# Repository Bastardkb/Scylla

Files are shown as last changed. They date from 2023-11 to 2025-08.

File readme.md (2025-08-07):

# Scylla

A modern low-profile ergonomic split keyboard, with a number row and a feature-full thumb cluster.

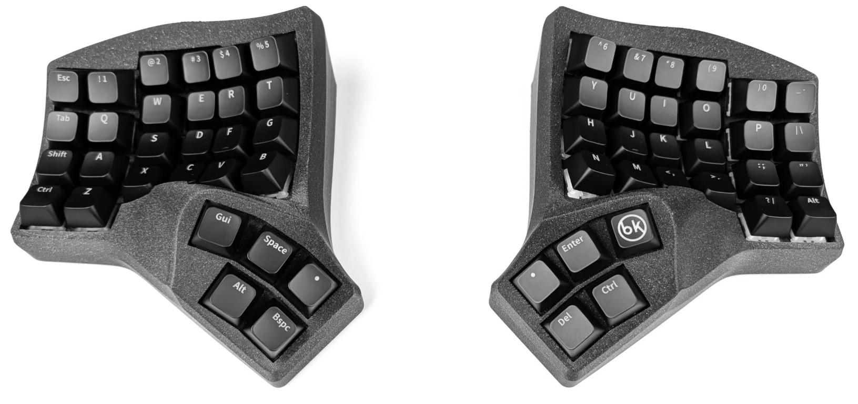
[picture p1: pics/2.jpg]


# Required components

## Electronic components

You will need to order the parts from a shop, and order some PCBs directly from the manufacturer.

Parts list:

| Part name | Amount | Link |
| --- | --- | --- |
| Flexible PCB for the plate | 2 | https://github.com/Bastardkb/Scylla-PCB-Plate |
| Flexible PCB for the thumbs | 2 | https://github.com/Bastardkb/Scylla-PCB-thumb-cluster |
| Splinktegrated* | 2 | https://github.com/bastardkb/splinktegrated |
| SOD123 Diodes | 10 | |
| BAT54C Diodes | 24 | |
| Cables | | 28 AWG recommended |
| M4 8mm Torx Screw | 16 | Conrad |
| M4 screw insert, M4 X D6.0 X L5.0 | 16 | https://fr.aliexpress.com/item/4000232925592.html?spm=a2g0s.12269583.0.0.6aef4f282LZO4v |
| Audio jack, SMD | 2 | |
| Button, 4x4x1.5 | 2 | https://www.aliexpress.com/item/1005001304569553.html?spm=a2g0s.9042311.0.0.27424c4dDwgcp7 |

*Alternatively, you can use the [Elite-C holder](https://github.com/Bastardkb/Elite-C-holder) with the [splinky](https://github.com/bastardkb/splinky) or any other [compatible board](https://docs.bastardkb.com/hw/rp2040-community.html). 

If you don't want to source the flexible PCBs, you can also use either amoebas or handwire.

If you want RGB, you will also need:

| Part name | Amount | Link |
| --- | --- | --- |
| SK6812 Mini-E LEDs | 58 | Aliexpress |
| Capacitor, 1uF | 4 | 1206 |
| Resistor, 330Ohms | 4 | 1206 |
| Wires | | 28 AWG recommended, Black, Red, Color |
| Ribbon cables Flexstrip | 6 | |

## Print the case

The STL files are included in this Github.
Feel free to use and modify them at length. The files are on a non-commercial license, so this is for personal projects only - please do not use those to sell them.

Please find detailed instructions on how to print the case on the online instructions linked below.

### Tent mount plate
This option allows the keyboard to be mounted to standard camera gear tripods and mounts.  
A 1/4 - 20 UNC 7.6 mm deep heat insert is needed.  

## Get a kit from BastardKB

You can get a full Kit, including case and all PCBs and electronics required on the shop:
https://bastardkb.com/

If you want to print the case yourself, you can also get just the electronics Kit.

# Build guide

You can find detailed instruction on the online documentation linked below.

# Links

- Discord: https://bastardkb.com/discord
- Website: https://bastardkb.com/
- Docs: https://docs.bastardkb.com
# License 

This work is licensed under a Creative Commons Attribution-NonCommercial-ShareAlike 4.0 International License.

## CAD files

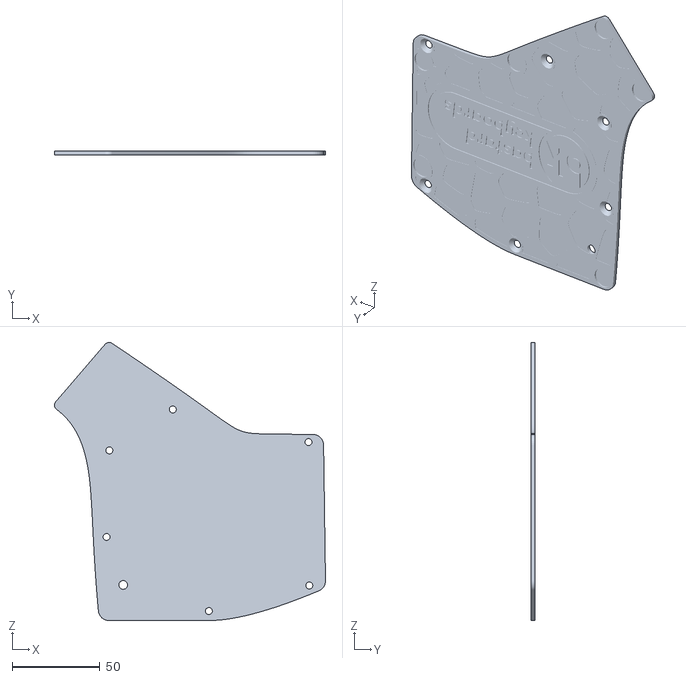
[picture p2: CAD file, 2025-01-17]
files/MK2/scylla_v3_36_plate_left.stl
154.5 x 2.00 x 158.5

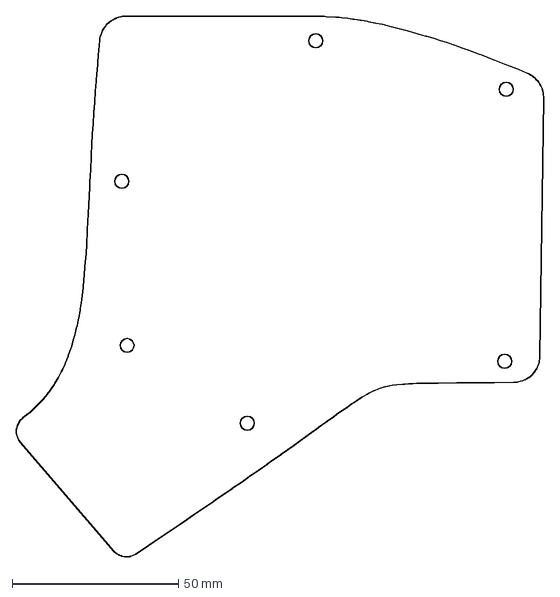
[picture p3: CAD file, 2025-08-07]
files/mods/MK2/metal plates/scylla_mk2_steel_plate.dxf
158.5 x 162.5 mm

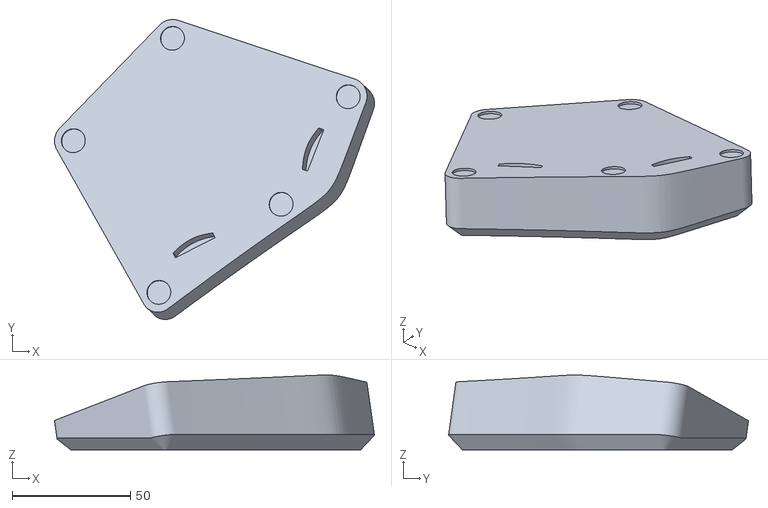
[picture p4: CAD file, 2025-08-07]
files/mods/MK2/palm-rest-mk2/obj_6_Scylla Palm rest.stl
135.6 x 127.1 x 31.7

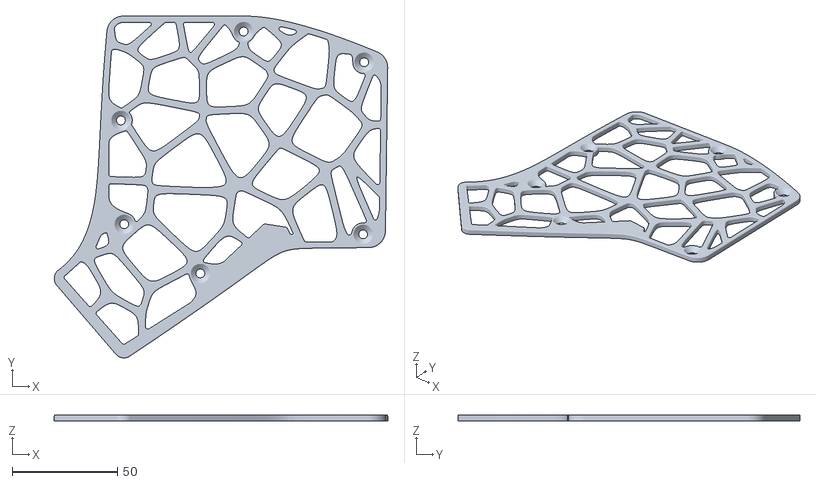
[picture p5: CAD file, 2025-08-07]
files/mods/MK2/scylla_mk2_voronoi_plate_alt.stl
158.5 x 162.5 x 3.00

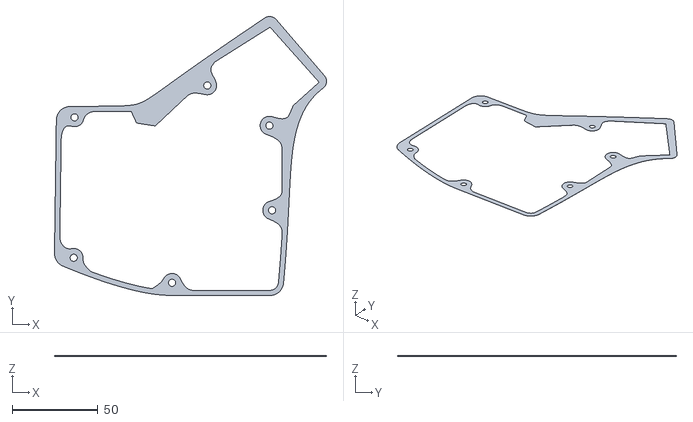
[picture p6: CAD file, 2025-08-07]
files/mods/MK2/metal plates/scylla_mk2_tpu_gasket_0.5mm.stl
158.5 x 162.5 x 0.5

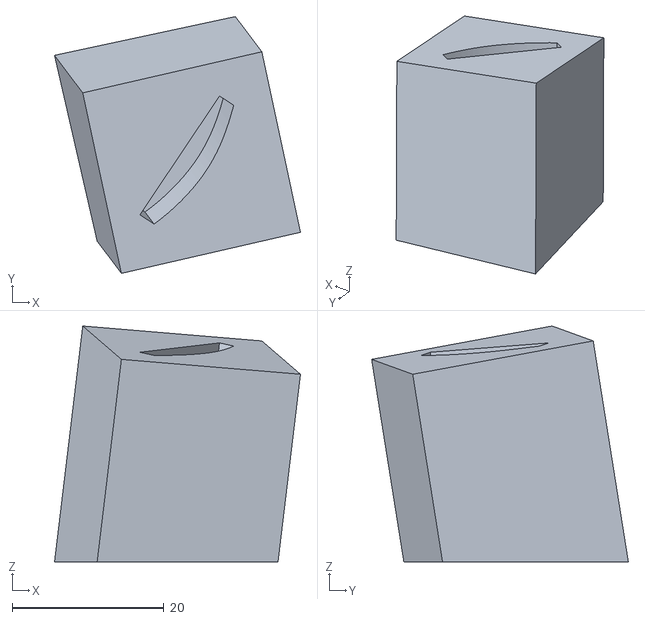
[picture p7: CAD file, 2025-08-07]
files/mods/MK2/palm-rest-mk2/obj_7_test fit.stl
32.4 x 33.9 x 31.1

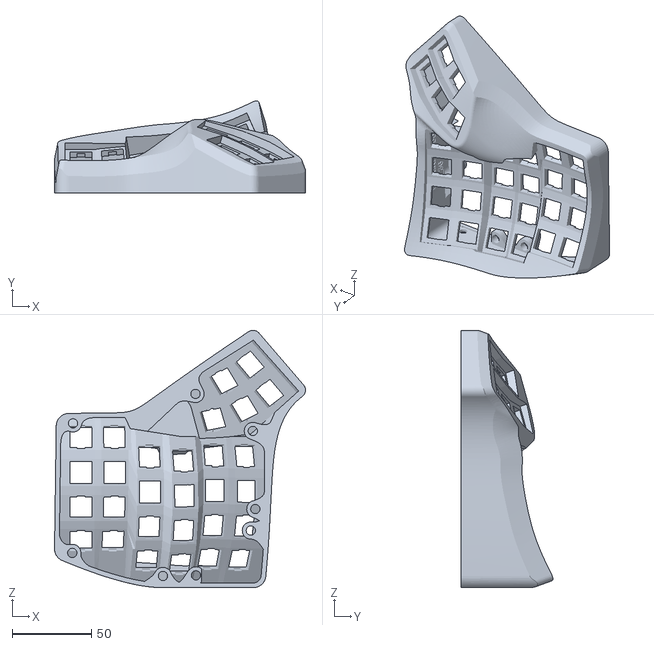
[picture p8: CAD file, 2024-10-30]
files/MK2/scylla_v3_36.stl
158.5 x 58.1 x 162.5

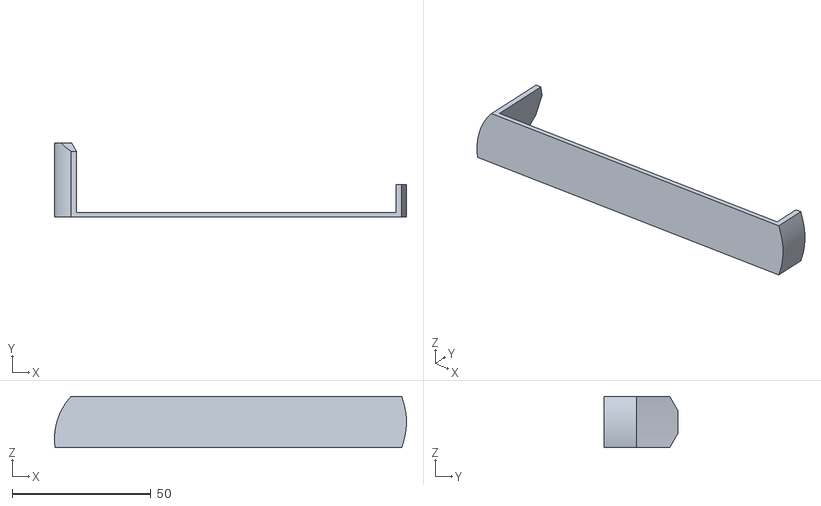
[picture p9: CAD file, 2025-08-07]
files/mods/MK2/palm-rest-mk2/obj_2_scylla hook .stl
127.0 x 26.7 x 18.6

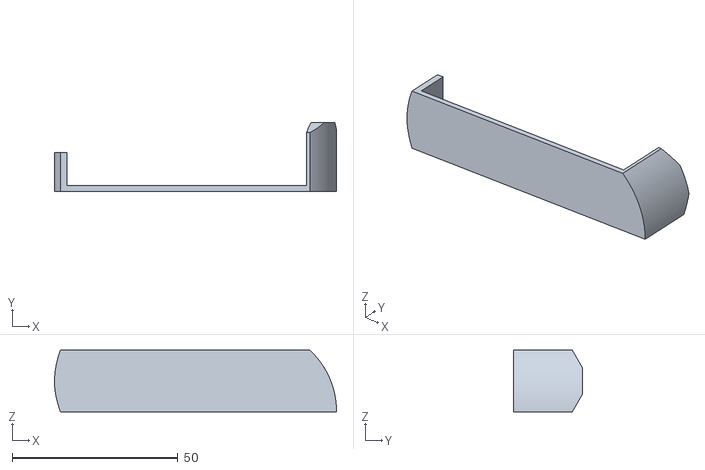
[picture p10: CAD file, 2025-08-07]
files/mods/MK2/palm-rest-mk2/obj_1_scylla hook 2.stl
85.1 x 20.7 x 18.6

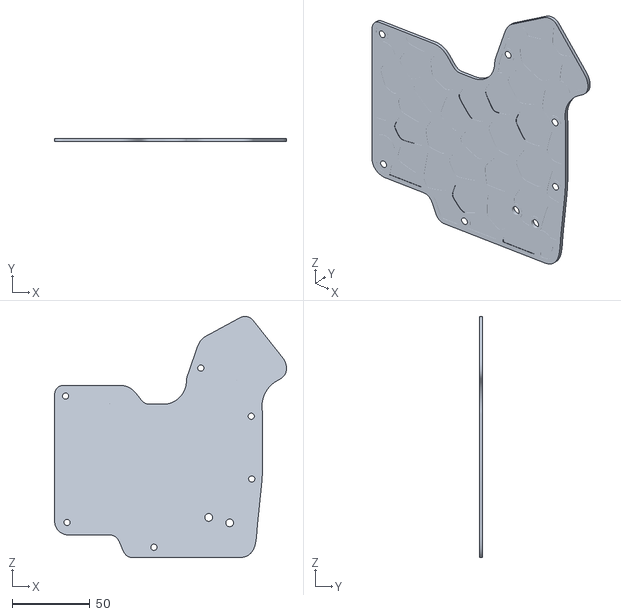
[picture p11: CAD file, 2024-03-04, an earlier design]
files/MK1/plate_shield2.x_voronoi.stl
149.5 x 2.00 x 155.3

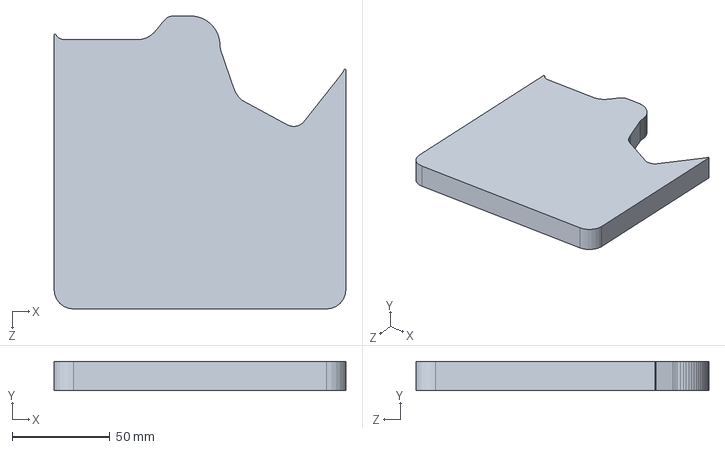
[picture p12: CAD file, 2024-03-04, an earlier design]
files/mods/MK1/palm-rest/Scylla-PlamRest-Straight.SLDPRT
149.5 x 15.0 x 150.0 mm

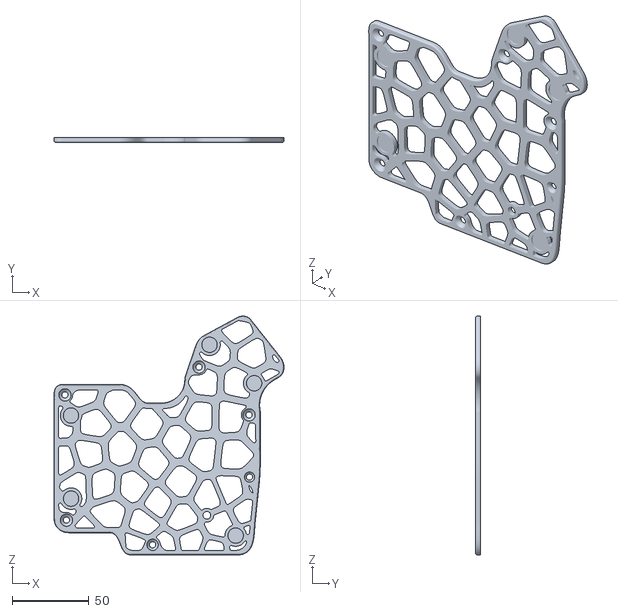
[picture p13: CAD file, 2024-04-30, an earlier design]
files/mods/MK1/plate_shield2.x_voronoi_alt.stl
149.5 x 3.00 x 155.3

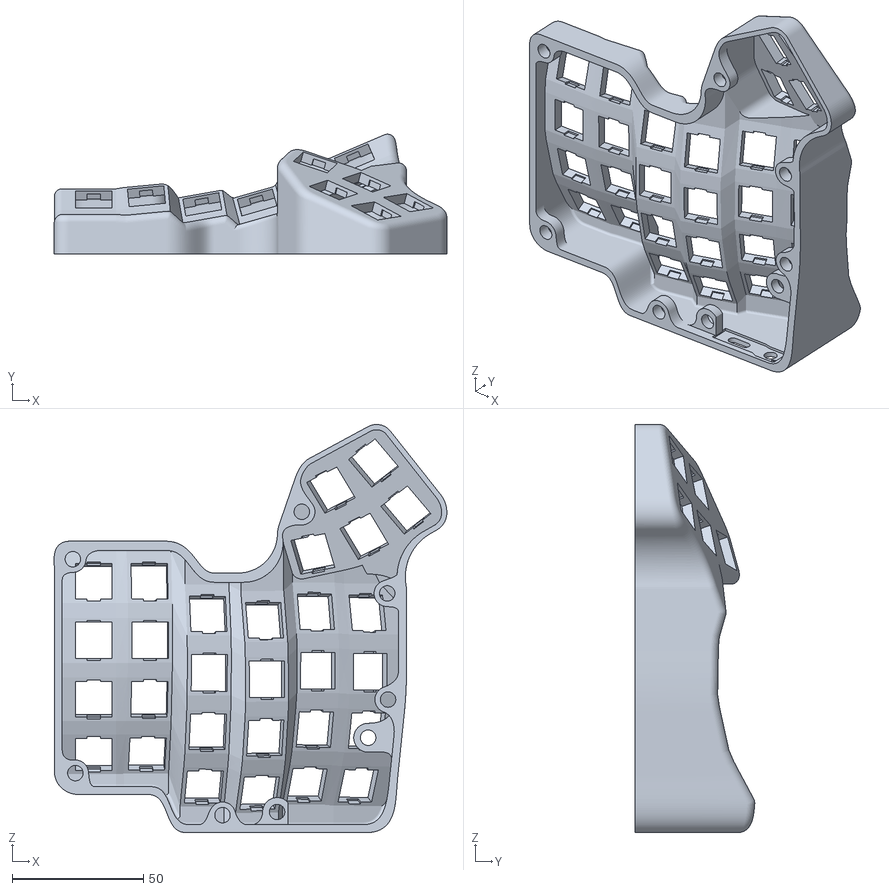
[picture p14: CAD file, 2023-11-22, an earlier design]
files/MK1/scylla2.1.stl
149.5 x 45.5 x 155.3

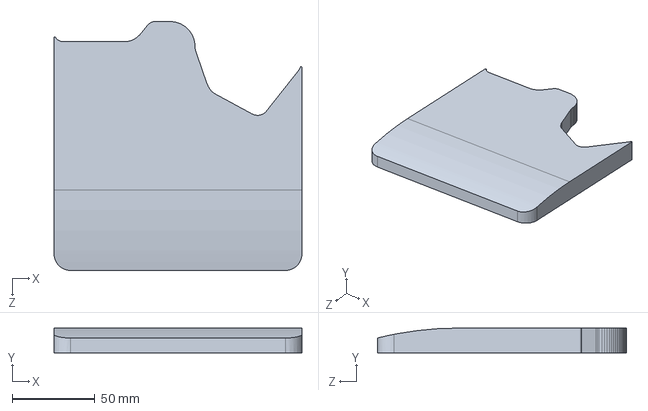
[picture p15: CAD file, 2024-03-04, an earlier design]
files/mods/MK1/palm-rest/Scylla-PlamRest-Slope.SLDPRT
149.5 x 15.0 x 150.0 mm

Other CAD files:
files/MK2/scylla_v3_36_plate_right.stl
files/mods/MK2/palm-rest-mk2/obj_5_Scylla Palm rest.stl
files/mods/MK2/palm-rest-mk2/obj_4_scylla hook .stl
files/mods/MK2/palm-rest-mk2/obj_3_scylla hook 2.stl
files/MK1/plate_shield2.x.dxf
files/MK1/plate_shield2.x.stl
files/MK1/tent30deg_v8.stl
files/MK1/tent_mount_shield.stl
files/mods/MK1/palm-rest/Scylla-PlamRest-Slope.DWG
files/mods/MK1/palm-rest/Scylla-PlamRest-Slope.STL
files/mods/MK1/palm-rest/Scylla-PlamRest-Straight.DWG
files/mods/MK1/palm-rest/Scylla-PlamRest-Straight.STL

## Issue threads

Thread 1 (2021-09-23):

3D Printing settings

JGrzybowski, 2021-09-23:
Thanks for sharing 3D files for Scylla I wanted to build one for a long time using amoebas.

Are there any recommended settings regarding printing?
Like:
- infill %
- layer height
- support type
- printing material (I saw PLA in the store but do you know how others do)

bstiq, 2021-09-24:
Hello,

Glad to know you're building a Scylla !

On the Github there's a *Print the case *section, with a link to the
documentation on the exact print settings and filaments.

Regards,

*Quentin LEBASTARD*

Le jeu. 23 sept. 2021 à 16:51, Jan Grzybowski ***@***.***> a
écrit :

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

Closed 2021-09-28.

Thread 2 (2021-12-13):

How do I get the right-hand side part?

yelcat, 2021-12-13:
This repository just contain the left side, how do I get the right-hand side part?

bstiq, 2021-12-15:
Hello,

You can mirror it in your slicer before generating the g-code.

Regards,

yelcat, 2021-12-16:
Thank You, I got

Quentin ***@***.***>于2021年12月16日 周四上午4:38写道：

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

Closed 2021-12-15.

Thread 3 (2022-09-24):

SOD123 Diodes, but the circuit uses BAT54C

AlgusDark, 2022-09-24:
As the titles says, it seems that the diodes should be different. Or did I print a different one? This according the Readme.

AlgusDark, 2022-09-24:
Ohh, the thumb clusters uses SOD123 and the other circuit is BAT54c

bstiq, 2022-11-25:
Yes

Closed 2022-11-25.

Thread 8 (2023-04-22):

BAT54c not included in parts list

nikolai-franke, 2023-04-22:
Hey, the parts list only mentions the SOD123 diodes, but BAT54c diodes are also required, right?

bstiq, 2023-05-28:
Hello,

That's correct, that's a relic from when I used PCBs with only SOD123 diodes.
Thanks for the tip ! I fixed the BOM.

Closed 2023-05-28.

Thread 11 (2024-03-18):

Make list of 3d parts to print

bstiq, 2024-03-18:
With the add of a few more plates, adding a 3d parts list like on the charybdis repo sounds necessary.
Then, we can also move the title up, and move the electronic components list to a separate BOM file like on the charybdis repo.

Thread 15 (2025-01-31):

Wrong link for printable shield adapter

hasrthur, 2025-01-31:
At the moment it points to https://github.com/Bastardkb/Skeletyl/blob/main/things/pro%20micro%20mount%20plate/pro%20micro%20mount%20plate%20v2.stl but I believe it should be https://github.com/Bastardkb/Skeletyl/blob/main/mods/pro%20micro%20mount%20plate/pro%20micro%20mount%20plate%20v2.stl

Closed 2025-01-31.

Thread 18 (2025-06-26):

STEP files

poll-busily, 2025-06-26:
Thanks for the really nice designs. I'd like to make a CNC-milled Scylla in aluminium but haven't had much luck converting the STL files into STEP format. Could the STEP files for the MK2 case be added here? I see that other board repos (like the TBK Mini) have these.

bstiq, 2025-06-27:
Hello,

At the moment I don't have plans to open source the MK2 step files.

Regards,
Quentin Lebastard
Bastard Keyboards

Closed 2025-06-27.

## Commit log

2021-07-18 add stls
    [Scylla79.stl, platev77.stl, tent30deg_v79.stl]
2021-07-18 fix amount of screws
2021-07-28 update reset buttotn position
    [platev77.stl, platev79.stl]
2021-08-04 fix screws and rst button hole alignment
    [platev80.stl]
2021-08-05 fix screw hole orientation
    [tent30deg_v5.stl, tent30deg_v79.stl]
2021-09-20 update port size and position
    [Scylla79.stl, Scylla82.stl]
2022-02-25 update pcb links
2022-05-27 easier to install screws in tents
    [tent30deg_v5.stl, tent30deg_v8.stl]
2022-07-20 remove old plate
    [platev80.stl]
2023-02-25 Added new plate
    [tent_mount_shield.stl]
2023-05-19 splinktegrated plate
    [plate_shield2.x.stl, plate_shield2.x_splinktegrated.stl]
2023-11-22 easier thumb cluster
    [Scylla82.stl, scylla2.1.stl]
2023-11-30 Added Scylla-PalmRest files
    stl, dwg(auto cad), SLDPRT(solidworks)
    [Scylla-PlamRest-Slope.DWG, Scylla-PlamRest-Slope.SLDPRT, Scylla-PlamRest-Slope.STL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]
2024-03-04 add voronoi plate
    [plate_shield2.x.dxf, plate_shield2.x.stl, plate_shield2.x_splinktegrated.dxf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]
2024-03-12 add alternative voronoi styled plate
    [plate_shield2.x_voronoi_alt.stl]
2024-03-13 move files to mods folder
    [Scylla-PlamRest-Slope.DWG, Scylla-PlamRest-Slope.SLDPRT, Scylla-PlamRest-Slope.STL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]
2024-04-28 upload updated voronoi plate
    [plate_shield2.x_voronoi_alt.stl]
2024-10-23 add mk1/mk2 folders
    [plate_shield2.x.dxf, plate_shield2.x.stl, plate_shield2.x_voronoi.stl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]
2025-01-17 update plates with logo
    [scylla_v3_36_plate_left.stl, scylla_v3_36_plate_right.stl]
2025-01-31 #15 Fix the link to the printable shield adapter
2025-08-04 update BOM
2025-08-06 uploaded files for printing TPU gaskets and lasercut metal plates
    [scylla_mk2_steel_plate.dxf, scylla_mk2_tpu_gasket_0.5mm.stl]
2025-08-06 add voronoi plate for mk2 scylla
    [scylla_mk2_voronoi_plate_alt.stl]
2025-08-07 add palm rest mod, move files around
    [Scylla-PlamRest-Slope.DWG, Scylla-PlamRest-Slope.SLDPRT, Scylla-PlamRest-Slope.STL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]
2025-08-07 move mk2 voronoi plate
    [scylla_mk2_voronoi_plate_alt.stl]
2025-08-07 move files into mods folder
    [scylla_mk2_steel_plate.dxf, scylla_mk2_tpu_gasket_0.5mm.stl]
2026-03-05 move old files to mk1 folder
    [tent30deg_v8.stl, tent_mount_shield.stl]
